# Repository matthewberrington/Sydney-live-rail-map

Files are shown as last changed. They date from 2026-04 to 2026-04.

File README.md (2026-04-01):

# Sydney-live-train-map

Plan of features:
- [ ] Visualisation of Sydney's L2 & L3 light rail
- [ ] Real time visualisation of tram positions and directions
- [ ] Geographically accurate rail map, extracted from Open Street Map data
- [ ] Geographically accurate silkscreen showing shoreline and points of interest
- [ ] Identify L2 vs L3 trams, and inbound vs outbound from Circulay Quay using different colour encodings of RGB LEDs
- [ ] Legend showing LED colour encoding
- [ ] Seven segment display showing time-to-departure of next service from UNSW Anzac Parade
- [ ] LEDs showing status of connecting rail network (T1, T2, T3, T4, T8, M1, M3, L1)
- [ ] Silscreen tracks of other rail lines (eg, City Circle, Lines south of central)
- [ ] Wi-Fi connectivity
- [ ] Adjustable brightness
- [ ] Train icons at interchanges on silkscreen (T in a circle)
- [ ] L1 line on silkscreen
- [ ] Centenial park 
- [ ] Sydney Harbour bridge

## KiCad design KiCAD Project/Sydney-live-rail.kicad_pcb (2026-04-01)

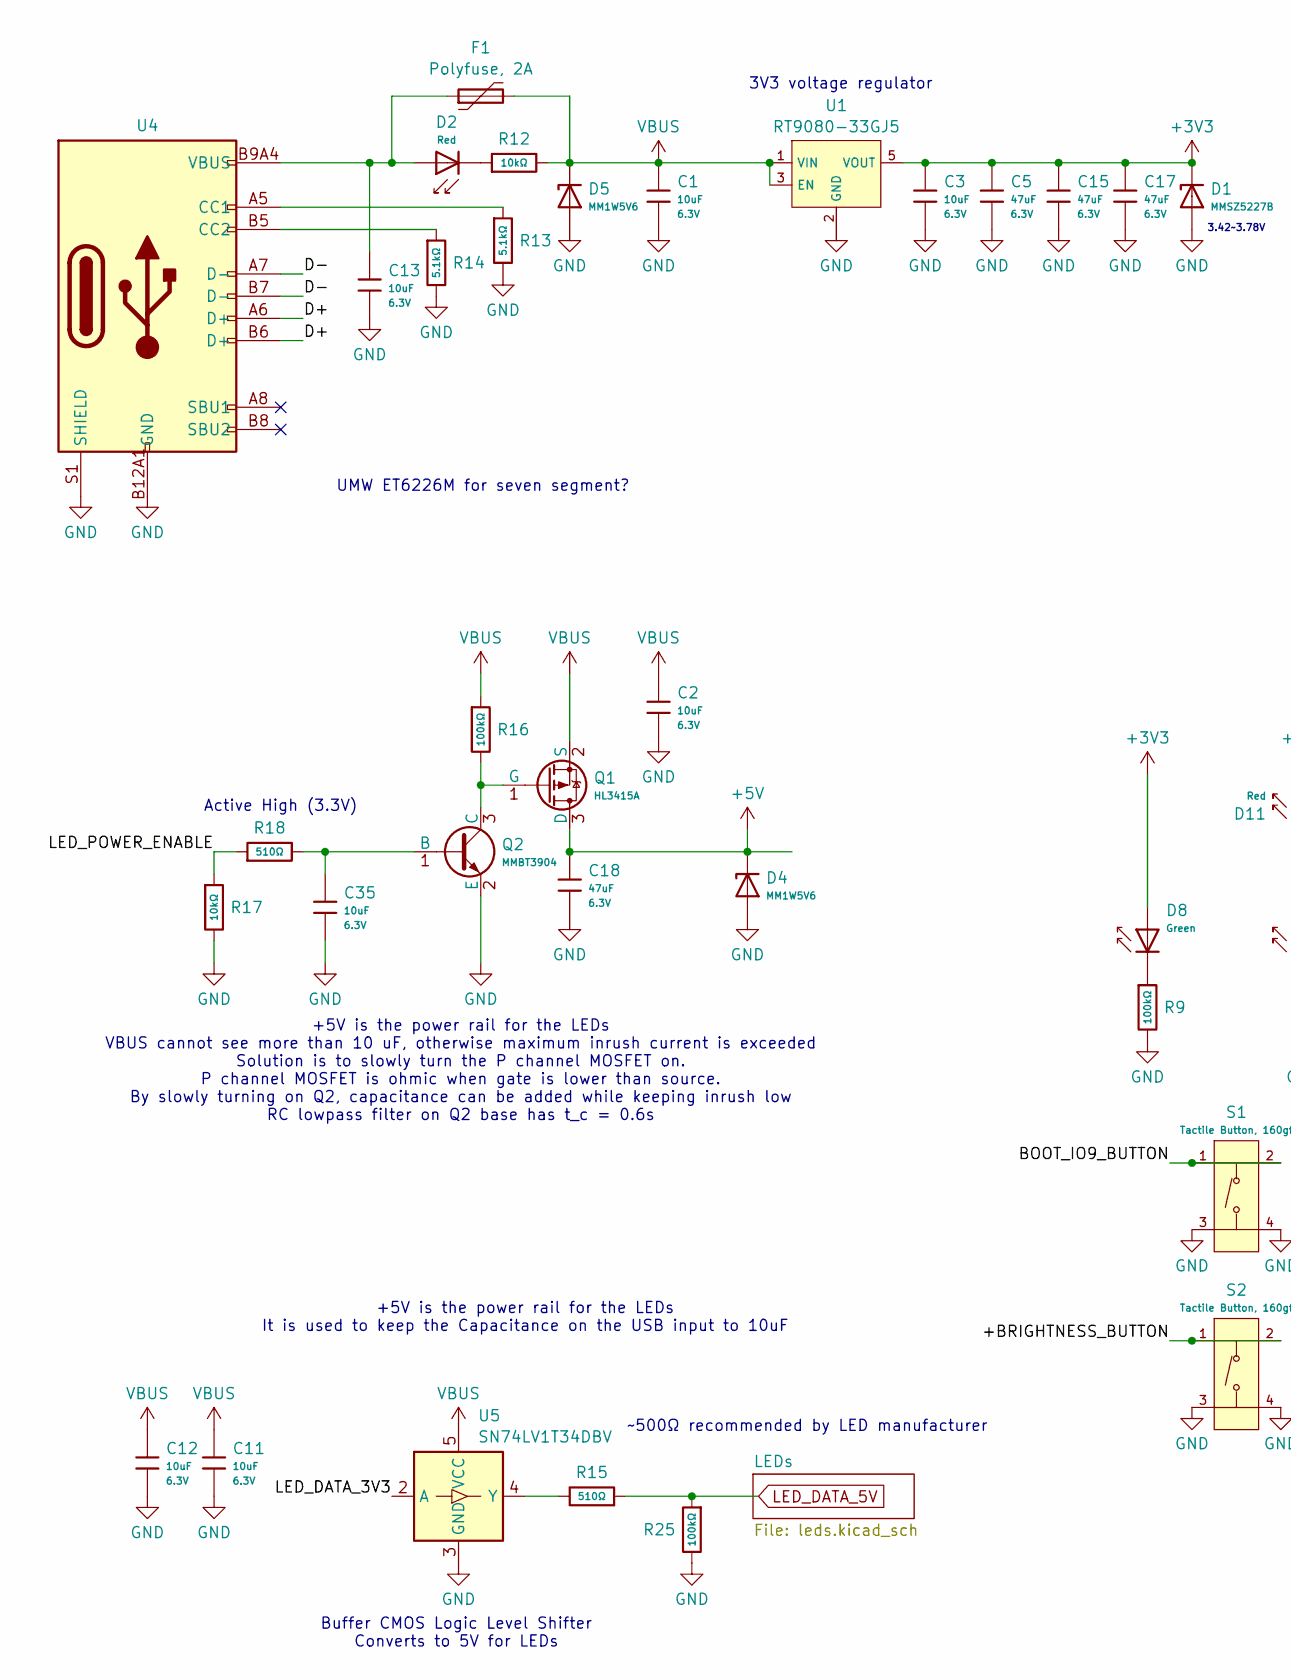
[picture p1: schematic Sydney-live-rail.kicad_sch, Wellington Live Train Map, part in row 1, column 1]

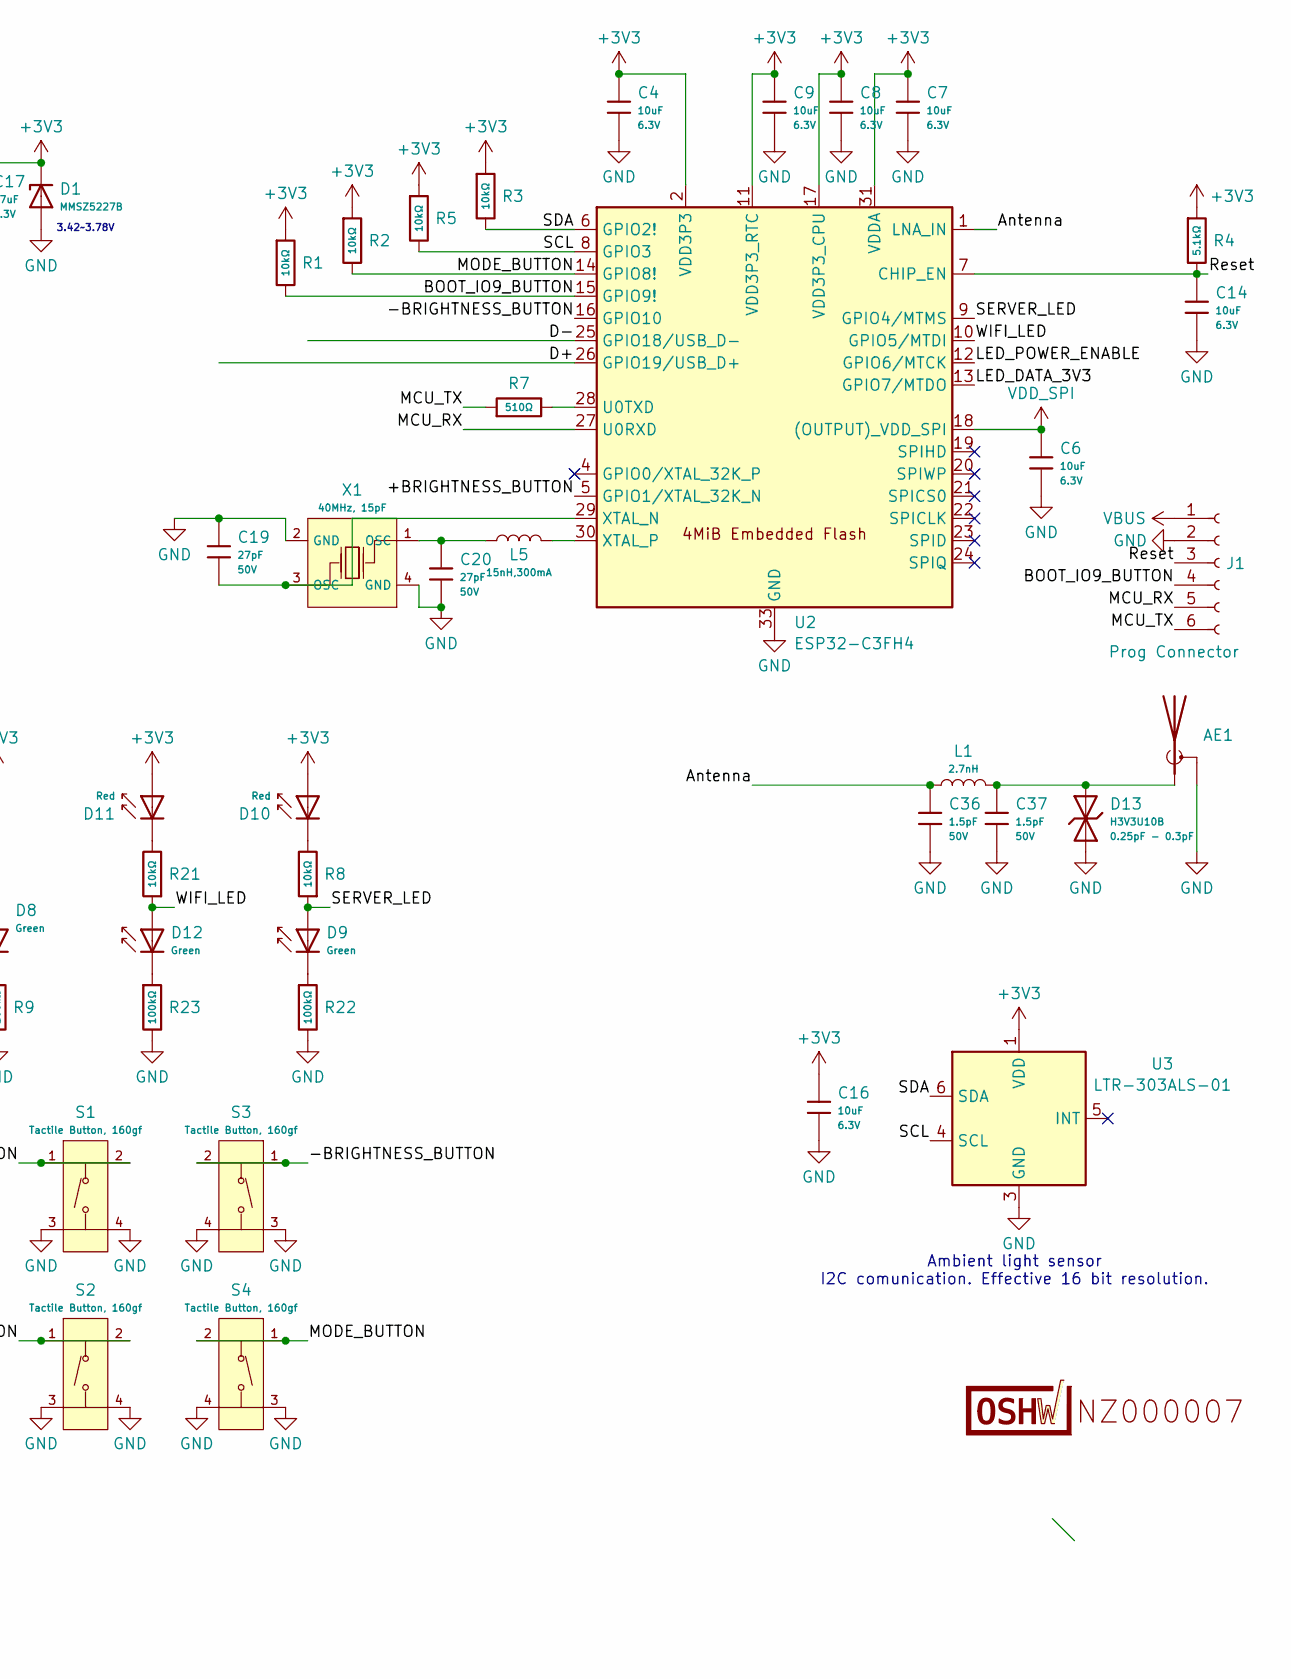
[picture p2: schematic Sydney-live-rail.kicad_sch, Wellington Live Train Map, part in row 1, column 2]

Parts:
AE1: Antenna_Shield; Inverted_F_Antenna_2.4Ghz_1.0mmPCB_TI_CC2430DB.pretty
C1, C2, C3, C4, C6, C7, C8, C9, C11, C12, C13, C14, C16, C35: 10uF; C_0402; Voltage Rated 6.3V; Tolerance ±20%; Part CL05A106MQ5NUNC; LCSC C15525
C5, C15, C17, C18: 47uF; C_0805; Voltage Rated 6.3V; Tolerance ±20%; Part CL21A476MQYNNNE; LCSC C16780
C19, C20: 27pF; C_0402; Voltage Rated 50V; Tolerance ±5%; Part 0402CG270J500NT; LCSC C1557
C36, C37: 1.5pF; C_0402; Voltage Rated 50V; Part 0402CG1R5C500NT; LCSC C1552
D1: MMSZ5227B; D_SOD-123; Part MMSZ5227B; LCSC C22395553
D2, D10, D11: Red; D_0805; Forward Voltage (VF) 1.6V~2.6V; Part NCD0805R1; LCSC C84256
D4, D5: MM1W5V6; D_SOD-123; Part MM1W5V6; LCSC C22435086
D8, D9, D12: Green; D_0805; Part KT-0805G; LCSC C2297
D13: H3V3U10B; D_DFN1006-2L; Part H3V3U10B; LCSC C20615782
F1: Polyfuse, 2A; Fuse_1206_3216Metric; Part SMD1206-200/06N; LCSC C6165195
J1: Prog Connector
L1: 2.7nH; L_0402; Part LQG15HS2N7S02D; LCSC C77108
L5: 15nH,300mA; L_0402; Tolerance ±5%; Part SDCL1005C15NJTDF; LCSC C27143
LOGO2: (no value)
Q1: HL3415A; Q_SOT-23; Part HL3415A; LCSC C28646270
Q2: MMBT3904; Q_SOT-23; Part MMBT3904; LCSC C7420353
R1, R2, R3, R5, R8, R12, R17, R21: 10kΩ; R_0402; Overload Voltage (Max) 50V; Tolerance ±1%; Part 0402WGF1002TCE; LCSC C25744
R4, R13, R14: 5.1kΩ; R_0402; Overload Voltage (Max) 50V; Tolerance ±1%; Part 0402WGF5101TCE; LCSC C25905
R7, R15, R18: 510Ω; R_0402; Overload Voltage (Max) 50V; Tolerance ±1%; Part 0402WGF5100TCE; LCSC C25123
R9, R16, R22, R23, R25: 100kΩ; R_0402; Overload Voltage (Max) 50V; Tolerance ±1%; Part 0402WGF1003TCE; LCSC C25741
S1, S2, S3, S4: Tactile Button, 160gf; SW-SMD_4P-L5.1-W5.1-P3.70-LS6.5-TL-2; Voltage Rating (Dc) 12V; Part TS-1187A-B-A-B; LCSC C318884
U1: RT9080-33GJ5; TSOT-23-5; Part RT9080-33GJ5; LCSC C841192
U2: ESP32-C3FH4; QFN-32-1EP_5x5mm_P0.5mm_EP3.7x3.7mm_ThermalVias; Part ESP32-C3FH4; LCSC C2858491
U3: LTR-303ALS-01; Lite-On_LTR-303ALS-01; Part LTR-303ALS-01; LCSC C364577
U4: Connector, USB-TYPE-C-16P; TYPE-C-SMD_HX-TYPE-C-16PIN; Part USB-TYPE-C-019; LCSC C2927039
U5: SN74LV1T34DBV; SOT-23-5; Part SN74LV1T34DBVR; LCSC C100024
X1: 40MHz, 15pF; OSC-SMD_4P-L3.2-W2.5-BL_SIT8008BI; Part X322540MPB4SI; LCSC C9010

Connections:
+3V3: C3.1, C4.1, C5.1, C7.1, C8.1, C9.1, C15.1, C16.1, C17.1, D1.1, D8.2, D10.2, D11.2, R1.1, R2.1, R3.1, R4.1, R5.1, U1.5 (VOUT), U2.2 (VDD3P3), U2.3 (VDD3P3), U2.11 (VDD3P3_RTC), U2.17 (VDD3P3_CPU), U2.31 (VDDA), U2.32 (VDDA), U3.1 (VDD)
+5V: C18.1, D4.1, Q1.3 (D); also elsewhere on the board
/+BRIGHTNESS_BUTTON: S2.1 (A), S2.2 (B), U2.5 (GPIO1/XTAL_32K_N)
/-BRIGHTNESS_BUTTON: S3.1 (A), S3.2 (B), U2.16 (GPIO10)
/Antenna: C36.1, L1.1, U2.1 (LNA_IN)
/BOOT_IO9_BUTTON: J1.4, R1.2, S1.1 (A), S1.2 (B), U2.15 (GPIO9!)
/D+: U2.26 (GPIO19/USB_D+), U4.A6 (D+), U4.B6 (D+)
/D-: U2.25 (GPIO18/USB_D-), U4.A7 (D-), U4.B7 (D-)
/LED_DATA_3V3: U2.13 (GPIO7/MTDO), U5.2 (A)
/LED_POWER_ENABLE: R17.1, R18.1, U2.12 (GPIO6/MTCK)
/MCU_RX: J1.5, U2.27 (U0RXD)
/MCU_TX: J1.6, R7.1
/MODE_BUTTON: R2.2, S4.1 (A), S4.2 (B), U2.14 (GPIO8!)
/Reset: C14.1, J1.3, R4.2, U2.7 (CHIP_EN)
/SCL: R5.2, U2.8 (GPIO3), U3.4 (SCL)
/SDA: R3.2, U2.6 (GPIO2!), U3.6 (SDA)
/SERVER_LED: D9.2, R8.1, U2.9 (GPIO4/MTMS)
/WIFI_LED: D12.2, R21.1, U2.10 (GPIO5/MTDI)
GND: AE1.2 (Shield), C1.2, C2.2, C3.2, C4.2, C5.2, C6.2, C7.2, C8.2, C9.2, C11.2, C12.2, C13.2, C14.2, C15.2, C16.2, C17.2, C18.2, C19.1, C20.2, C35.2, C36.2, C37.2, D1.2, D4.2, D5.2, D13.1, J1.2, Q2.2 (E), R9.2, R13.2, R14.2, R17.2, R22.2, R23.2, R25.2, S1.3 (C), S1.4 (D), S2.3 (C), S2.4 (D), S3.3 (C), S3.4 (D), S4.3 (C), S4.4 (D), U1.2 (GND), U2.33 (GND), U3.3 (GND), U4.A12B1 (GND), U4.B12A1 (GND), U4.S1 (SHIELD), U5.3 (GND), X1.2 (GND), X1.4 (GND); also elsewhere on the board
LED_DATA_5V: R15.1, R25.1; also elsewhere on the board
unnamed: AE1.1 (A), C37.1, D13.2, L1.2
unnamed: C13.1, D2.2, F1.1, U4.A9B4 (VBUS), U4.B9A4 (VBUS)
unnamed: C20.1, L5.1, X1.1 (OSC)
unnamed: D2.1, R12.1
unnamed: D8.1, R9.1
unnamed: D9.1, R22.1
unnamed: D10.1, R8.2
unnamed: D11.1, R21.2
unnamed: D12.1, R23.1
unnamed: Q1.1 (G), Q2.3 (C), R16.2
unnamed: C35.1, Q2.1 (B), R18.2
unnamed: R7.2, U2.28 (U0TXD)
unnamed: C19.2, U2.29 (XTAL_N), X1.3 (OSC)
unnamed: L5.2, U2.30 (XTAL_P)
unnamed: R13.1, U4.A5 (CC1)
unnamed: R14.1, U4.B5 (CC2)
unnamed: R15.2, U5.4 (Y)
VBUS: C1.1, C2.1, C11.1, C12.1, D5.1, F1.2, J1.1, Q1.2 (S), R12.2, R16.1, U1.1 (VIN), U1.3 (EN), U5.5 (VCC)
VDD_SPI: C6.1, U2.18 ((OUTPUT)_VDD_SPI)

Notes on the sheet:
Active High (3.3V)
+5V is the power rail for the LEDs VBUS cannot see more than 10 uF, otherwise maximum inrush current is exceeded Solution is to slowly turn the P channel MOSFET on. P channel MOSFET is ohmic when gate is lower than source. By slowly turning on Q2, capacitance can be added while keeping inrush low R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
Ambient light sensor I2C comunication. Effective 16 bit resolution.
UMW ET6226M for seven segment?
3V3 voltage regulator
Buffer CMOS Logic Level Shifter Converts to 5V for LEDs
3.42~3.78V
~500Ω recommended by LED manufacturer
+5V is the power rail for the LEDs It is used to keep the Capacitance on the USB input to 10uF

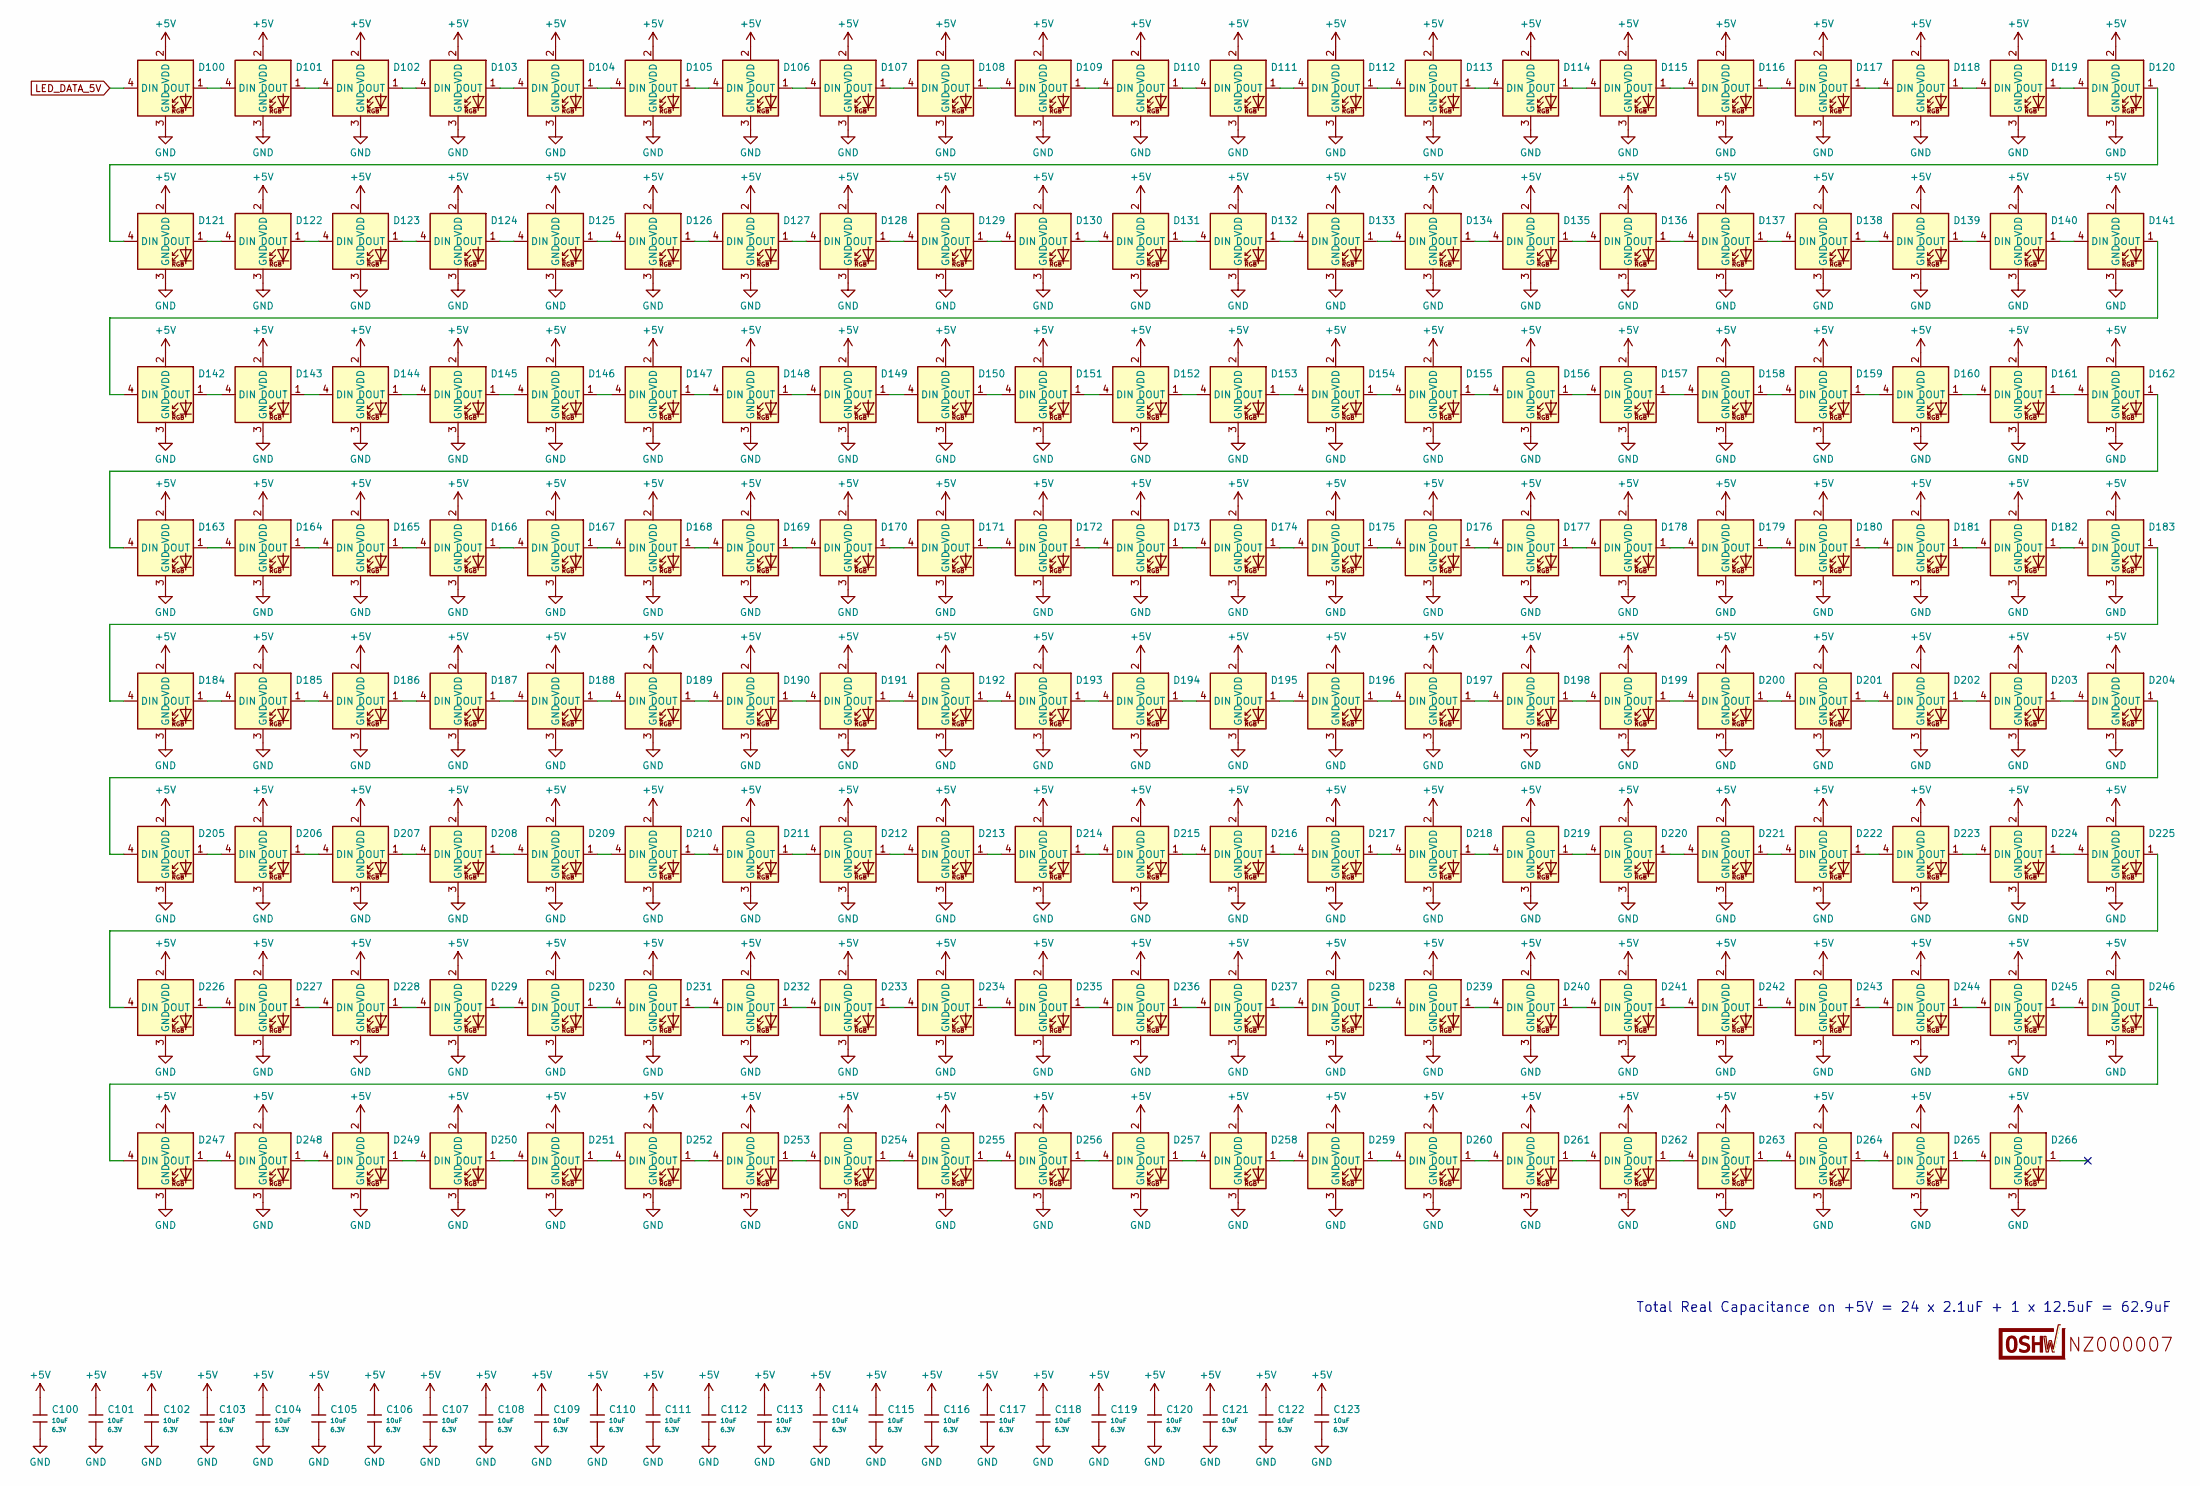
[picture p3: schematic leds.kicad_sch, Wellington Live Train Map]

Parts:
C100, C101, C102, C103, C104, C105, C106, C107, C108, C109, C110, C111, C112, C113, C114, C115, C116, C117, C118, C119, C120, C121, C122, C123: 10uF; C_0402; Voltage Rated 6.3V; Tolerance ±20%; Part CL05A106MQ5NUNC; LCSC C15525
D100, D101, D102, D103, D104, D105, D106, D107, D108, D109, D110, D111, D112, D113, D114, D115, D116, D117, D118, D119, D120, D121, D122, D123, D124, D125, D126, D127, D128, D129, D130, D131, D132, D133, D134, D135, D136, D137, D138, D139, D140, D141, D142, D143, D144, D145, D146, D147, D148, D149, D150, D151, D152, D153, D154, D155, D156, D157, D158, D159, D160, D161, D162, D163, D164, D165, D166, D167, D168, D169, D170, D171, D172, D173, D174, D175, D176, D177, D178, D179, D180, D181, D182, D183, D184, D185, D186, D187, D188, D189, D190, D191, D192, D193, D194, D195, D196, D197, D198, D199, D200, D201, D202, D203, D204, D205, D206, D207, D208, D209, D210, D211, D212, D213, D214, D215, D216, D217, D218, D219, D220, D221, D222, D223, D224, D225, D226, D227, D228, D229, D230, D231, D232, D233, D234, D235, D236, D237, D238, D239, D240, D241, D242, D243, D244, D245, D246, D247, D248, D249, D250, D251, D252, D253, D254, D255, D256, D257, D258, D259, D260, D261, D262, D263, D264, D265, D266: XL-1615RGBC-WS2812B-S; LED-SMD_4P-L1.6-W1.5_XL-1615RGBC-WS2812B; Part XL-1615RGBC-WS2812B-S; LCSC C41413180
LOGO1: (no value)

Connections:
+5V: C100.1, C101.1, C102.1, C103.1, C104.1, C105.1, C106.1, C107.1, C108.1, C109.1, C110.1, C111.1, C112.1, C113.1, C114.1, C115.1, C116.1, C117.1, C118.1, C119.1, C120.1, C121.1, C122.1, C123.1, D100.2 (VDD), D101.2 (VDD), D102.2 (VDD), D103.2 (VDD), D104.2 (VDD), D105.2 (VDD), D106.2 (VDD), D107.2 (VDD), D108.2 (VDD), D109.2 (VDD), D110.2 (VDD), D111.2 (VDD), D112.2 (VDD), D113.2 (VDD), D114.2 (VDD), D115.2 (VDD), D116.2 (VDD), D117.2 (VDD), D118.2 (VDD), D119.2 (VDD), D120.2 (VDD), D121.2 (VDD), D122.2 (VDD), D123.2 (VDD), D124.2 (VDD), D125.2 (VDD), D126.2 (VDD), D127.2 (VDD), D128.2 (VDD), D129.2 (VDD), D130.2 (VDD), D131.2 (VDD), D132.2 (VDD), D133.2 (VDD), D134.2 (VDD), D135.2 (VDD), D136.2 (VDD), D137.2 (VDD), D138.2 (VDD), D139.2 (VDD), D140.2 (VDD), D141.2 (VDD), D142.2 (VDD), D143.2 (VDD), D144.2 (VDD), D145.2 (VDD), D146.2 (VDD), D147.2 (VDD), D148.2 (VDD), D149.2 (VDD), D150.2 (VDD), D151.2 (VDD), D152.2 (VDD), D153.2 (VDD), D154.2 (VDD), D155.2 (VDD), D156.2 (VDD), D157.2 (VDD), D158.2 (VDD), D159.2 (VDD), D160.2 (VDD), D161.2 (VDD), D162.2 (VDD), D163.2 (VDD), D164.2 (VDD), D165.2 (VDD), D166.2 (VDD), D167.2 (VDD), D168.2 (VDD), D169.2 (VDD), D170.2 (VDD), D171.2 (VDD), D172.2 (VDD), D173.2 (VDD), D174.2 (VDD), D175.2 (VDD), D176.2 (VDD), D177.2 (VDD), D178.2 (VDD), D179.2 (VDD), D180.2 (VDD), D181.2 (VDD), D182.2 (VDD), D183.2 (VDD), D184.2 (VDD), D185.2 (VDD), D186.2 (VDD), D187.2 (VDD), D188.2 (VDD), D189.2 (VDD), D190.2 (VDD), D191.2 (VDD), D192.2 (VDD), D193.2 (VDD), D194.2 (VDD), D195.2 (VDD), D196.2 (VDD), D197.2 (VDD), D198.2 (VDD), D199.2 (VDD), D200.2 (VDD), D201.2 (VDD), D202.2 (VDD), D203.2 (VDD), D204.2 (VDD), D205.2 (VDD), D206.2 (VDD), D207.2 (VDD), D208.2 (VDD), D209.2 (VDD), D210.2 (VDD), D211.2 (VDD), D212.2 (VDD), D213.2 (VDD), D214.2 (VDD), D215.2 (VDD), D216.2 (VDD), D217.2 (VDD), D218.2 (VDD), D219.2 (VDD), D220.2 (VDD), D221.2 (VDD), D222.2 (VDD), D223.2 (VDD), D224.2 (VDD), D225.2 (VDD), D226.2 (VDD), D227.2 (VDD), D228.2 (VDD), D229.2 (VDD), D230.2 (VDD), D231.2 (VDD), D232.2 (VDD), D233.2 (VDD), D234.2 (VDD), D235.2 (VDD), D236.2 (VDD), D237.2 (VDD), D238.2 (VDD), D239.2 (VDD), D240.2 (VDD), D241.2 (VDD), D242.2 (VDD), D243.2 (VDD), D244.2 (VDD), D245.2 (VDD), D246.2 (VDD), D247.2 (VDD), D248.2 (VDD), D249.2 (VDD), D250.2 (VDD), D251.2 (VDD), D252.2 (VDD), D253.2 (VDD), D254.2 (VDD), D255.2 (VDD), D256.2 (VDD), D257.2 (VDD), D258.2 (VDD), D259.2 (VDD), D260.2 (VDD), D261.2 (VDD), D262.2 (VDD), D263.2 (VDD), D264.2 (VDD), D265.2 (VDD), D266.2 (VDD); also elsewhere on the board
GND: C100.2, C101.2, C102.2, C103.2, C104.2, C105.2, C106.2, C107.2, C108.2, C109.2, C110.2, C111.2, C112.2, C113.2, C114.2, C115.2, C116.2, C117.2, C118.2, C119.2, C120.2, C121.2, C122.2, C123.2, D100.3 (GND), D101.3 (GND), D102.3 (GND), D103.3 (GND), D104.3 (GND), D105.3 (GND), D106.3 (GND), D107.3 (GND), D108.3 (GND), D109.3 (GND), D110.3 (GND), D111.3 (GND), D112.3 (GND), D113.3 (GND), D114.3 (GND), D115.3 (GND), D116.3 (GND), D117.3 (GND), D118.3 (GND), D119.3 (GND), D120.3 (GND), D121.3 (GND), D122.3 (GND), D123.3 (GND), D124.3 (GND), D125.3 (GND), D126.3 (GND), D127.3 (GND), D128.3 (GND), D129.3 (GND), D130.3 (GND), D131.3 (GND), D132.3 (GND), D133.3 (GND), D134.3 (GND), D135.3 (GND), D136.3 (GND), D137.3 (GND), D138.3 (GND), D139.3 (GND), D140.3 (GND), D141.3 (GND), D142.3 (GND), D143.3 (GND), D144.3 (GND), D145.3 (GND), D146.3 (GND), D147.3 (GND), D148.3 (GND), D149.3 (GND), D150.3 (GND), D151.3 (GND), D152.3 (GND), D153.3 (GND), D154.3 (GND), D155.3 (GND), D156.3 (GND), D157.3 (GND), D158.3 (GND), D159.3 (GND), D160.3 (GND), D161.3 (GND), D162.3 (GND), D163.3 (GND), D164.3 (GND), D165.3 (GND), D166.3 (GND), D167.3 (GND), D168.3 (GND), D169.3 (GND), D170.3 (GND), D171.3 (GND), D172.3 (GND), D173.3 (GND), D174.3 (GND), D175.3 (GND), D176.3 (GND), D177.3 (GND), D178.3 (GND), D179.3 (GND), D180.3 (GND), D181.3 (GND), D182.3 (GND), D183.3 (GND), D184.3 (GND), D185.3 (GND), D186.3 (GND), D187.3 (GND), D188.3 (GND), D189.3 (GND), D190.3 (GND), D191.3 (GND), D192.3 (GND), D193.3 (GND), D194.3 (GND), D195.3 (GND), D196.3 (GND), D197.3 (GND), D198.3 (GND), D199.3 (GND), D200.3 (GND), D201.3 (GND), D202.3 (GND), D203.3 (GND), D204.3 (GND), D205.3 (GND), D206.3 (GND), D207.3 (GND), D208.3 (GND), D209.3 (GND), D210.3 (GND), D211.3 (GND), D212.3 (GND), D213.3 (GND), D214.3 (GND), D215.3 (GND), D216.3 (GND), D217.3 (GND), D218.3 (GND), D219.3 (GND), D220.3 (GND), D221.3 (GND), D222.3 (GND), D223.3 (GND), D224.3 (GND), D225.3 (GND), D226.3 (GND), D227.3 (GND), D228.3 (GND), D229.3 (GND), D230.3 (GND), D231.3 (GND), D232.3 (GND), D233.3 (GND), D234.3 (GND), D235.3 (GND), D236.3 (GND), D237.3 (GND), D238.3 (GND), D239.3 (GND), D240.3 (GND), D241.3 (GND), D242.3 (GND), D243.3 (GND), D244.3 (GND), D245.3 (GND), D246.3 (GND), D247.3 (GND), D248.3 (GND), D249.3 (GND), D250.3 (GND), D251.3 (GND), D252.3 (GND), D253.3 (GND), D254.3 (GND), D255.3 (GND), D256.3 (GND), D257.3 (GND), D258.3 (GND), D259.3 (GND), D260.3 (GND), D261.3 (GND), D262.3 (GND), D263.3 (GND), D264.3 (GND), D265.3 (GND), D266.3 (GND); also elsewhere on the board
LED_DATA_5V: D100.4 (DIN); also elsewhere on the board
unnamed: D100.1 (DOUT), D101.4 (DIN)
unnamed: D101.1 (DOUT), D102.4 (DIN)
unnamed: D102.1 (DOUT), D103.4 (DIN)
unnamed: D103.1 (DOUT), D104.4 (DIN)
unnamed: D104.1 (DOUT), D105.4 (DIN)
unnamed: D105.1 (DOUT), D106.4 (DIN)
unnamed: D106.1 (DOUT), D107.4 (DIN)
unnamed: D107.1 (DOUT), D108.4 (DIN)
unnamed: D108.1 (DOUT), D109.4 (DIN)
unnamed: D109.1 (DOUT), D110.4 (DIN)
unnamed: D110.1 (DOUT), D111.4 (DIN)
unnamed: D111.1 (DOUT), D112.4 (DIN)
unnamed: D112.1 (DOUT), D113.4 (DIN)
unnamed: D113.1 (DOUT), D114.4 (DIN)
unnamed: D114.1 (DOUT), D115.4 (DIN)
unnamed: D115.1 (DOUT), D116.4 (DIN)
unnamed: D116.1 (DOUT), D117.4 (DIN)
unnamed: D117.1 (DOUT), D118.4 (DIN)
unnamed: D118.1 (DOUT), D119.4 (DIN)
unnamed: D119.1 (DOUT), D120.4 (DIN)
unnamed: D120.1 (DOUT), D121.4 (DIN)
unnamed: D121.1 (DOUT), D122.4 (DIN)
unnamed: D122.1 (DOUT), D123.4 (DIN)
unnamed: D123.1 (DOUT), D124.4 (DIN)
unnamed: D124.1 (DOUT), D125.4 (DIN)
unnamed: D125.1 (DOUT), D126.4 (DIN)
unnamed: D126.1 (DOUT), D127.4 (DIN)
unnamed: D127.1 (DOUT), D128.4 (DIN)
unnamed: D128.1 (DOUT), D129.4 (DIN)
unnamed: D129.1 (DOUT), D130.4 (DIN)
unnamed: D130.1 (DOUT), D131.4 (DIN)
unnamed: D131.1 (DOUT), D132.4 (DIN)
unnamed: D132.1 (DOUT), D133.4 (DIN)
unnamed: D133.1 (DOUT), D134.4 (DIN)
unnamed: D134.1 (DOUT), D135.4 (DIN)
unnamed: D135.1 (DOUT), D136.4 (DIN)
unnamed: D136.1 (DOUT), D137.4 (DIN)
unnamed: D137.1 (DOUT), D138.4 (DIN)
unnamed: D138.1 (DOUT), D139.4 (DIN)
unnamed: D139.1 (DOUT), D140.4 (DIN)
unnamed: D140.1 (DOUT), D141.4 (DIN)
unnamed: D141.1 (DOUT), D142.4 (DIN)
unnamed: D142.1 (DOUT), D143.4 (DIN)
unnamed: D143.1 (DOUT), D144.4 (DIN)
unnamed: D144.1 (DOUT), D145.4 (DIN)
unnamed: D145.1 (DOUT), D146.4 (DIN)
unnamed: D146.1 (DOUT), D147.4 (DIN)
unnamed: D147.1 (DOUT), D148.4 (DIN)
unnamed: D148.1 (DOUT), D149.4 (DIN)
unnamed: D149.1 (DOUT), D150.4 (DIN)
unnamed: D150.1 (DOUT), D151.4 (DIN)
unnamed: D151.1 (DOUT), D152.4 (DIN)
unnamed: D152.1 (DOUT), D153.4 (DIN)
unnamed: D153.1 (DOUT), D154.4 (DIN)
unnamed: D154.1 (DOUT), D155.4 (DIN)
unnamed: D155.1 (DOUT), D156.4 (DIN)
unnamed: D156.1 (DOUT), D157.4 (DIN)
unnamed: D157.1 (DOUT), D158.4 (DIN)
unnamed: D158.1 (DOUT), D159.4 (DIN)
unnamed: D159.1 (DOUT), D160.4 (DIN)
unnamed: D160.1 (DOUT), D161.4 (DIN)
unnamed: D161.1 (DOUT), D162.4 (DIN)
unnamed: D162.1 (DOUT), D163.4 (DIN)
unnamed: D163.1 (DOUT), D164.4 (DIN)
unnamed: D164.1 (DOUT), D165.4 (DIN)
unnamed: D165.1 (DOUT), D166.4 (DIN)
unnamed: D166.1 (DOUT), D167.4 (DIN)
unnamed: D167.1 (DOUT), D168.4 (DIN)
unnamed: D168.1 (DOUT), D169.4 (DIN)
unnamed: D169.1 (DOUT), D170.4 (DIN)
unnamed: D170.1 (DOUT), D171.4 (DIN)
unnamed: D171.1 (DOUT), D172.4 (DIN)
unnamed: D172.1 (DOUT), D173.4 (DIN)
unnamed: D173.1 (DOUT), D174.4 (DIN)
unnamed: D174.1 (DOUT), D175.4 (DIN)
unnamed: D175.1 (DOUT), D176.4 (DIN)
unnamed: D176.1 (DOUT), D177.4 (DIN)
unnamed: D177.1 (DOUT), D178.4 (DIN)
unnamed: D178.1 (DOUT), D179.4 (DIN)
unnamed: D179.1 (DOUT), D180.4 (DIN)
unnamed: D180.1 (DOUT), D181.4 (DIN)
unnamed: D181.1 (DOUT), D182.4 (DIN)
unnamed: D182.1 (DOUT), D183.4 (DIN)
unnamed: D183.1 (DOUT), D184.4 (DIN)
unnamed: D184.1 (DOUT), D185.4 (DIN)
unnamed: D185.1 (DOUT), D186.4 (DIN)
unnamed: D186.1 (DOUT), D187.4 (DIN)
unnamed: D187.1 (DOUT), D188.4 (DIN)
unnamed: D188.1 (DOUT), D189.4 (DIN)
unnamed: D189.1 (DOUT), D190.4 (DIN)
unnamed: D190.1 (DOUT), D191.4 (DIN)
unnamed: D191.1 (DOUT), D192.4 (DIN)
unnamed: D192.1 (DOUT), D193.4 (DIN)
unnamed: D193.1 (DOUT), D194.4 (DIN)
unnamed: D194.1 (DOUT), D195.4 (DIN)
unnamed: D195.1 (DOUT), D196.4 (DIN)
unnamed: D196.1 (DOUT), D197.4 (DIN)
unnamed: D197.1 (DOUT), D198.4 (DIN)
unnamed: D198.1 (DOUT), D199.4 (DIN)
unnamed: D199.1 (DOUT), D200.4 (DIN)
unnamed: D200.1 (DOUT), D201.4 (DIN)
unnamed: D201.1 (DOUT), D202.4 (DIN)
unnamed: D202.1 (DOUT), D203.4 (DIN)
unnamed: D203.1 (DOUT), D204.4 (DIN)
unnamed: D204.1 (DOUT), D205.4 (DIN)
unnamed: D205.1 (DOUT), D206.4 (DIN)
unnamed: D206.1 (DOUT), D207.4 (DIN)
unnamed: D207.1 (DOUT), D208.4 (DIN)
unnamed: D208.1 (DOUT), D209.4 (DIN)
unnamed: D209.1 (DOUT), D210.4 (DIN)
unnamed: D210.1 (DOUT), D211.4 (DIN)
unnamed: D211.1 (DOUT), D212.4 (DIN)
unnamed: D212.1 (DOUT), D213.4 (DIN)
unnamed: D213.1 (DOUT), D214.4 (DIN)
unnamed: D214.1 (DOUT), D215.4 (DIN)
unnamed: D215.1 (DOUT), D216.4 (DIN)
unnamed: D216.1 (DOUT), D217.4 (DIN)
unnamed: D217.1 (DOUT), D218.4 (DIN)
unnamed: D218.1 (DOUT), D219.4 (DIN)
unnamed: D219.1 (DOUT), D220.4 (DIN)
unnamed: D220.1 (DOUT), D221.4 (DIN)
unnamed: D221.1 (DOUT), D222.4 (DIN)
unnamed: D222.1 (DOUT), D223.4 (DIN)
unnamed: D223.1 (DOUT), D224.4 (DIN)
unnamed: D224.1 (DOUT), D225.4 (DIN)
unnamed: D225.1 (DOUT), D226.4 (DIN)
unnamed: D226.1 (DOUT), D227.4 (DIN)
unnamed: D227.1 (DOUT), D228.4 (DIN)
unnamed: D228.1 (DOUT), D229.4 (DIN)
unnamed: D229.1 (DOUT), D230.4 (DIN)
unnamed: D230.1 (DOUT), D231.4 (DIN)
unnamed: D231.1 (DOUT), D232.4 (DIN)
unnamed: D232.1 (DOUT), D233.4 (DIN)
unnamed: D233.1 (DOUT), D234.4 (DIN)
unnamed: D234.1 (DOUT), D235.4 (DIN)
unnamed: D235.1 (DOUT), D236.4 (DIN)
unnamed: D236.1 (DOUT), D237.4 (DIN)
unnamed: D237.1 (DOUT), D238.4 (DIN)
unnamed: D238.1 (DOUT), D239.4 (DIN)
unnamed: D239.1 (DOUT), D240.4 (DIN)
unnamed: D240.1 (DOUT), D241.4 (DIN)
unnamed: D241.1 (DOUT), D242.4 (DIN)
unnamed: D242.1 (DOUT), D243.4 (DIN)
unnamed: D243.1 (DOUT), D244.4 (DIN)
unnamed: D244.1 (DOUT), D245.4 (DIN)
unnamed: D245.1 (DOUT), D246.4 (DIN)
unnamed: D246.1 (DOUT), D247.4 (DIN)
unnamed: D247.1 (DOUT), D248.4 (DIN)
unnamed: D248.1 (DOUT), D249.4 (DIN)
unnamed: D249.1 (DOUT), D250.4 (DIN)
unnamed: D250.1 (DOUT), D251.4 (DIN)
unnamed: D251.1 (DOUT), D252.4 (DIN)
unnamed: D252.1 (DOUT), D253.4 (DIN)
unnamed: D253.1 (DOUT), D254.4 (DIN)
unnamed: D254.1 (DOUT), D255.4 (DIN)
unnamed: D255.1 (DOUT), D256.4 (DIN)
unnamed: D256.1 (DOUT), D257.4 (DIN)
unnamed: D257.1 (DOUT), D258.4 (DIN)
unnamed: D258.1 (DOUT), D259.4 (DIN)
unnamed: D259.1 (DOUT), D260.4 (DIN)
unnamed: D260.1 (DOUT), D261.4 (DIN)
unnamed: D261.1 (DOUT), D262.4 (DIN)
unnamed: D262.1 (DOUT), D263.4 (DIN)
unnamed: D263.1 (DOUT), D264.4 (DIN)
unnamed: D264.1 (DOUT), D265.4 (DIN)
unnamed: D265.1 (DOUT), D266.4 (DIN)

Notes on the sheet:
Total Real Capacitance on +5V = 24 x 2.1uF + 1 x 12.5uF = 62.9uF

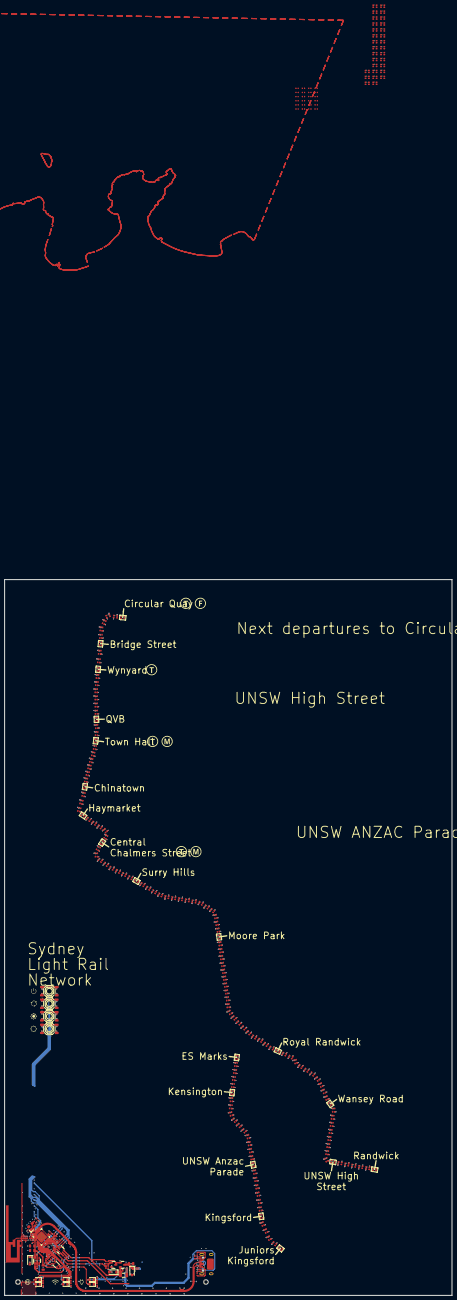
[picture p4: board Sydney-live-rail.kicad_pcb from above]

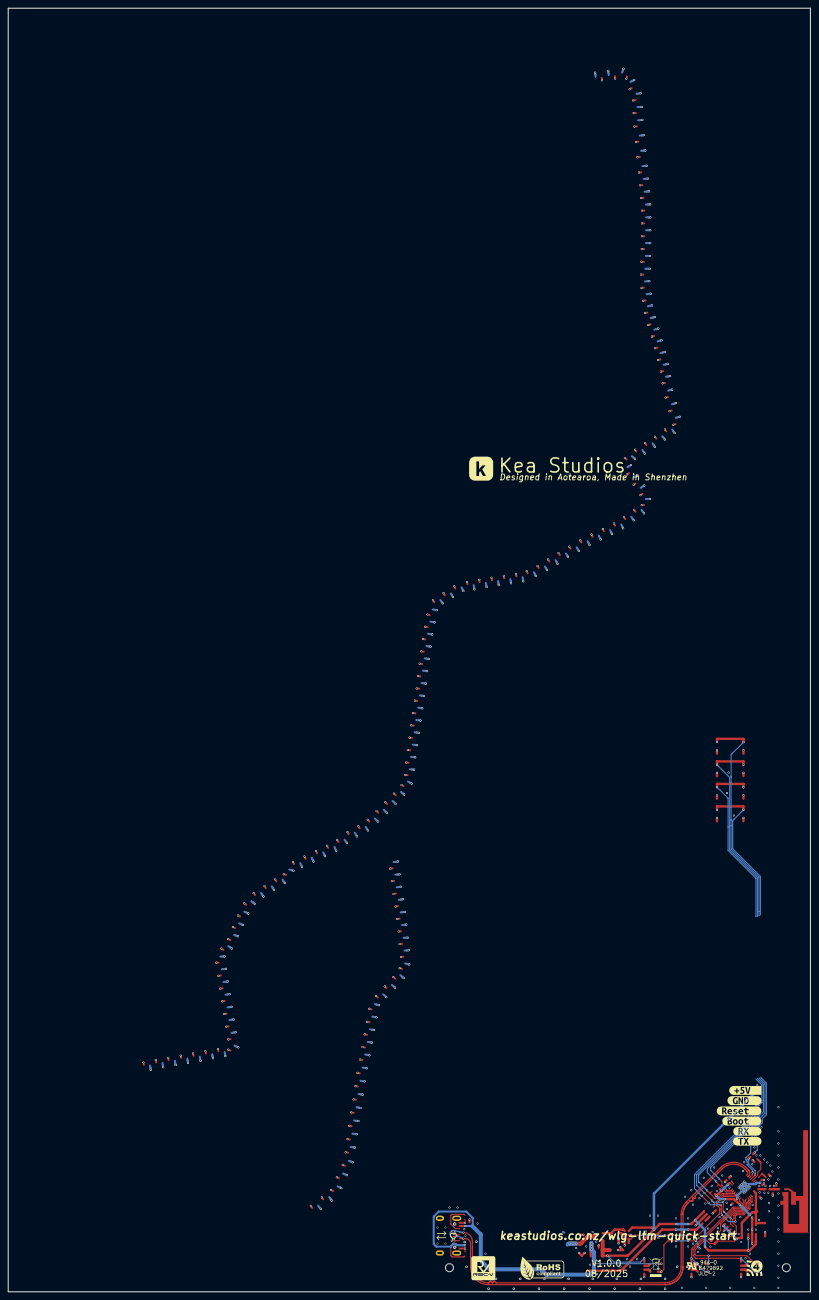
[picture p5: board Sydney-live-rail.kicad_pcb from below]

Board: 2 copper layers, 200.0 x 320.0 mm, 265 parts (6 on the bottom side), 205 nets.

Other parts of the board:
kibuzzard-68A93B9D: G***; kibuzzard-68A93B9D
kibuzzard-68A93BAB: G***; kibuzzard-68A93BAB
kibuzzard-68A93BBD: G***; kibuzzard-68A93BBD
kibuzzard-68A93BCF: G***; kibuzzard-68A93BCF
kibuzzard-68A93BEA: G***; kibuzzard-68A93BEA
kibuzzard-68A93BF1: G***; kibuzzard-68A93BF1

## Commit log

2025-10-24 Added annotations to schematic
    [Sydney-live-rail.kicad_pcb, Sydney-live-rail.kicad_sch, leds.kicad_sch]
2026-03-23 Make coasline pckl only include coastline within the PCB area
2026-03-24 Added digest track
2026-03-28 Got digest_track.py working to calculate position of LEDs
2026-03-30 Got LED placement working with correct orientation
2026-03-31 Got VSS automatically routed for LEDs
2026-03-31 Shifted PCB to be centred on page
2026-03-31 Added control electronics from Wellington project
    [Sydney-live-rail.kicad_pcb, Sydney-live-rail.kicad_sch]
2026-04-01 Added Metro icon
    [Sydney-live-rail.kicad_pcb]
2026-04-01 Added train lines to solder mask
2026-04-01 Fixed coastline so it's aligned with pcb
2026-04-01 Only plot train tracks within pcb boundary
2026-04-01 Added GND pour
2026-04-03 Fixed errors and warning on PCB
2026-04-03 Added ground planes aroung PCB
2026-04-03 Set sydney transport symbols to 5mm tall

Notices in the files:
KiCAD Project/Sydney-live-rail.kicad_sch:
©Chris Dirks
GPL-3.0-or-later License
